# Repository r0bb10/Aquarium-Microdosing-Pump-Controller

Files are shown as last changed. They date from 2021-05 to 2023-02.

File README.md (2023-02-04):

# Aquarium-Microdosing-Pump-Controller
Software for an ESP8266 base aquarium micro-dosing pump. Controlled through a local webpage. Currently hard-coded to control a single pump, the hardware supports up to four. 

Required Libraries:
Adafruit I2C FRAM Library
Adafruit RTClib
ESPAsyncWebServer
ESPAsyncTCP
NTPClient
ESP8266TimerInterrupt
#Alepiro85 Changelog: ESP_EEPROM by j-watson

Also needed:
Setting up Arduino IDE to support uploading files to SPIFFS: https://randomnerdtutorials.com/install-esp8266-filesystem-uploader-arduino-ide/

Required Hardware:
MB85RC256V I2C FRAM. This is for saving configurations without constantly writing to internal memory to prevent excessive wearing. 
#Alepiro85 Changelog: from version 0.1A: Not necessary, it is possible to save parameters on EEPROM
DS3231 RTC. For keeping track of time if wifi is unavailable. 

Known Problems:
Need to redesign PCB to be smaller and cheaper. Software is hard-coded for a single pump. 
#Alepiro85 Changelog: from Version 0.1B: Software manages 4 pumps control

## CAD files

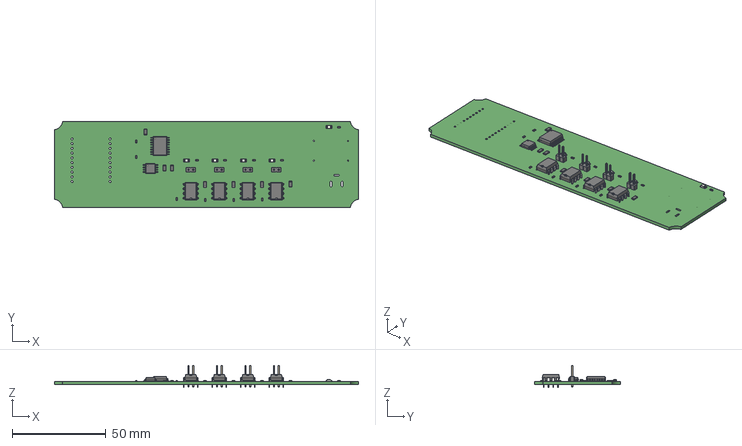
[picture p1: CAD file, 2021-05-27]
Hardware/Aquarium_Dosing_Pump_Controller/Aquarium_Dosing_Pump_Controller.step
162.6 x 45.7 x 11.8 mm

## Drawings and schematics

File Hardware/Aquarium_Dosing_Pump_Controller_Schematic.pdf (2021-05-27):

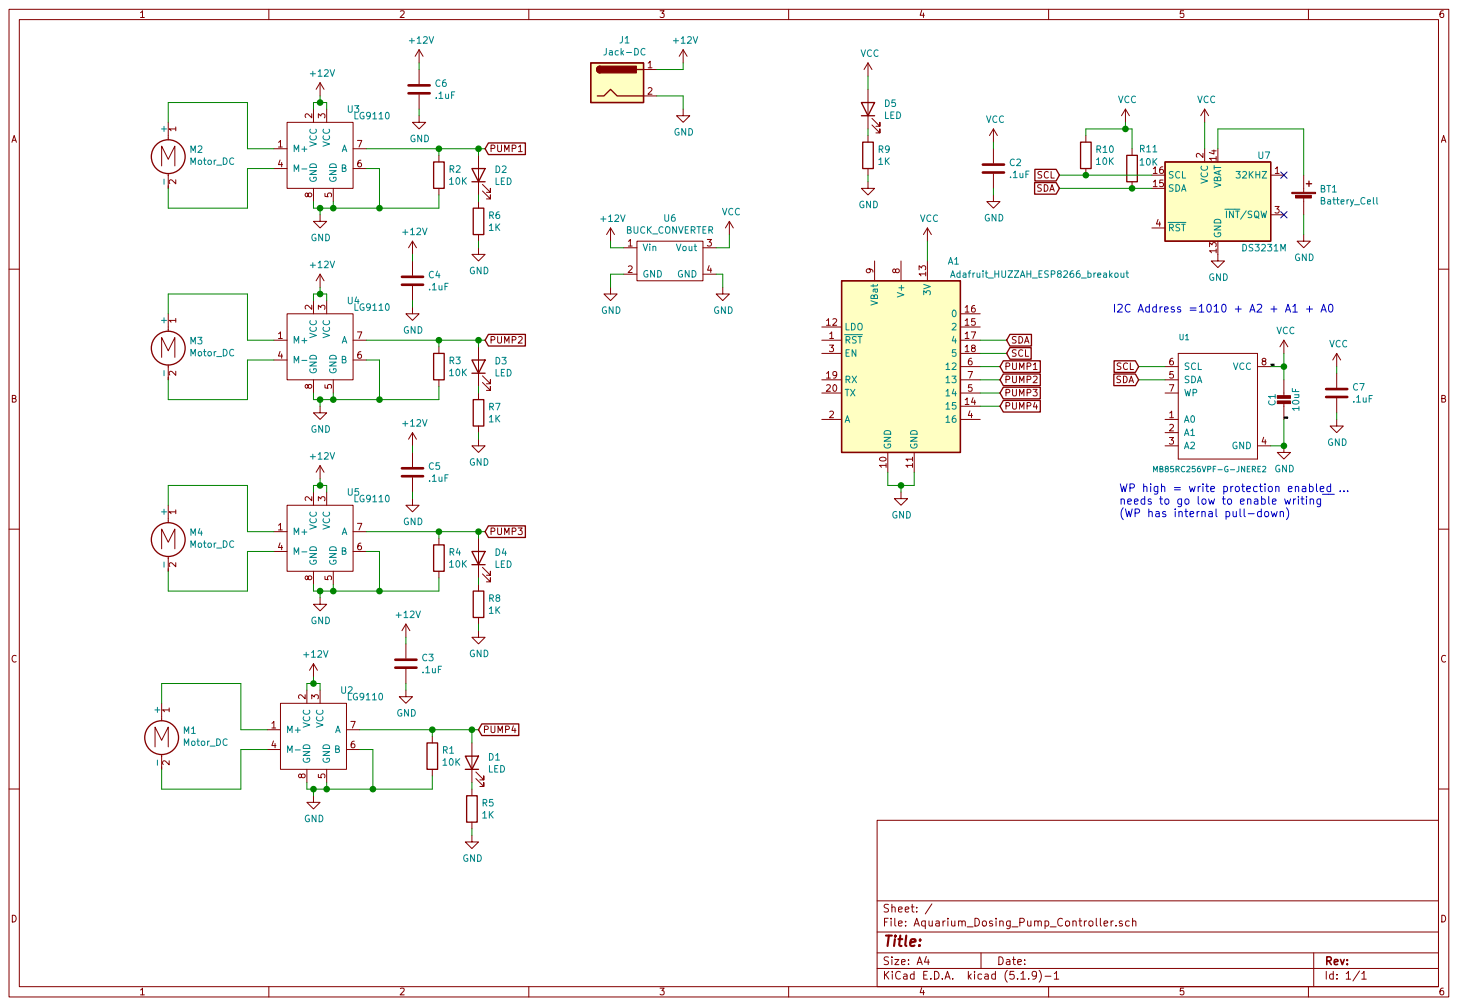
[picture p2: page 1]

VCC I2C Address =1010 + A2 + A1 + A0 WP high = write protection enabled ...

needs to go low to enable writing
(WP has internal pull-down)

File: Aquarium_Dosing_Pump_Controller.sch Sheet: / GND

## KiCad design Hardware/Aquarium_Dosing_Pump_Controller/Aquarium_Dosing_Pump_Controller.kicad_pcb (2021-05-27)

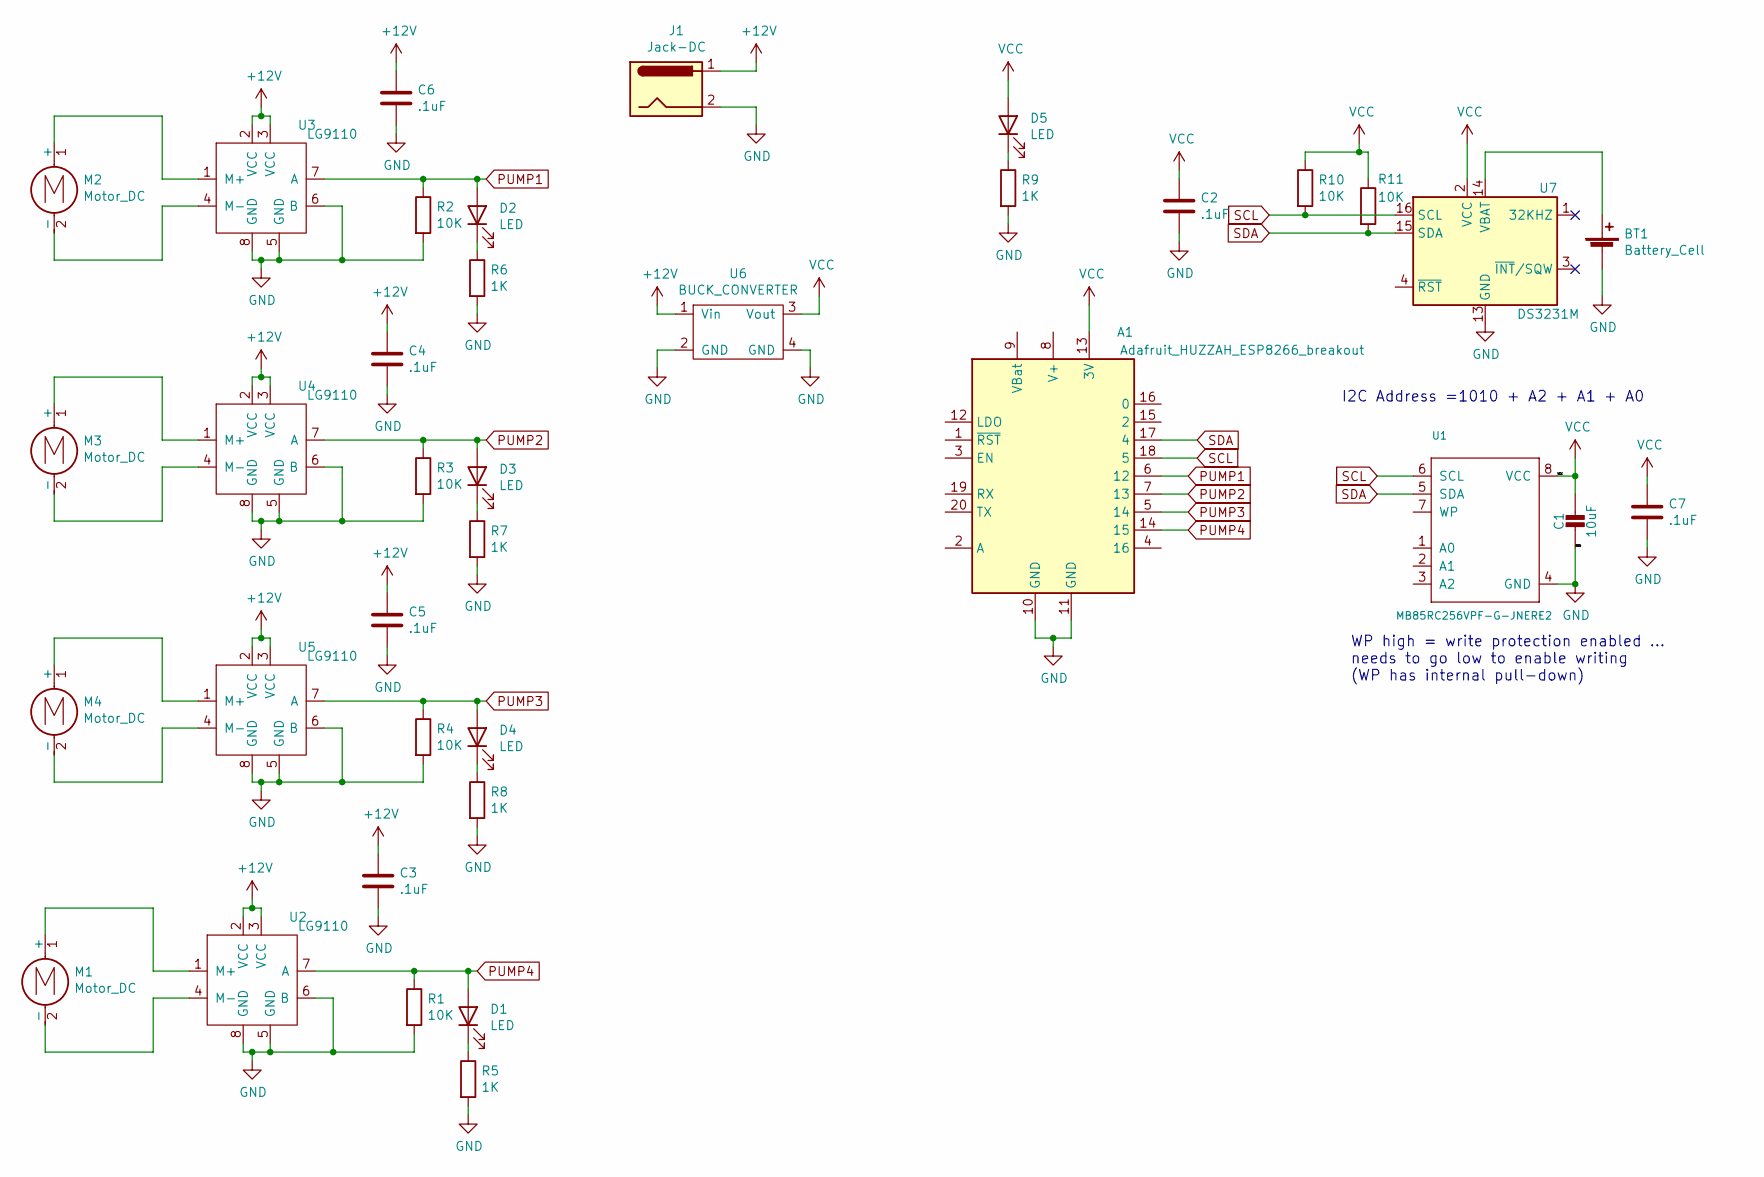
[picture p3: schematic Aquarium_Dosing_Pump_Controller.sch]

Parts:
A1: Adafruit_HUZZAH_ESP8266_breakout
BT1: Battery_Cell; CR1220
C1: 10uF; R_1206_3216Metric_Pad1.42x1.75mm_HandSolder
C2, C3, C4, C5, C6, C7: .1uF; R_1206_3216Metric_Pad1.42x1.75mm_HandSolder
D1, D2, D3, D4, D5: LED; LED_1206_3216Metric_Pad1.42x1.75mm_HandSolder
J1: Jack-DC; BarrelJack_Horizontal
M1, M2, M3, M4: Motor_DC; PinHeader_1x02_P2.54mm_Vertical
R1, R2, R3, R4, R10, R11: 10K; R_0603_1608Metric_Pad1.05x0.95mm_HandSolder
R5, R6, R7, R8, R9: 1K; R_0603_1608Metric_Pad1.05x0.95mm_HandSolder
U1: MB85RC256VPF-G-JNERE2; SOIJ-8_5.3x5.3mm_P1.27mm
U2, U3, U4, U5: LG9110; DIP-8_W7.62mm_LongPads
U6: BUCK_CONVERTER; Boost_Footprint
U7: DS3231M; SOIC-16W_7.5x10.3mm_P1.27mm

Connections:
+12V: C3.1, C4.1, C5.1, C6.1, J1.1, U2.2 (VCC), U2.3 (VCC), U3.2 (VCC), U3.3 (VCC), U4.2 (VCC), U4.3 (VCC), U5.2 (VCC), U5.3 (VCC), U6.1 (Vin)
GND: A1.10 (GND), A1.11 (GND), BT1.2 (-), C1.2, C2.2, C3.2, C4.2, C5.2, C6.2, C7.2, J1.2, R1.2, R2.2, R3.2, R4.2, R5.2, R6.2, R7.2, R8.2, R9.2, U1.4 (GND), U2.5 (GND), U2.6 (B), U2.8 (GND), U3.5 (GND), U3.6 (B), U3.8 (GND), U4.5 (GND), U4.6 (B), U4.8 (GND), U5.5 (GND), U5.6 (B), U5.8 (GND), U6.2 (GND), U6.4 (GND), U7.5 (GND), U7.6 (GND), U7.7 (GND), U7.8 (GND), U7.9 (GND), U7.10 (GND), U7.11 (GND), U7.12 (GND), U7.13 (GND)
unnamed: BT1.1 (+), U7.14 (VBAT)
unnamed: D1.1 (K), R5.1
unnamed: D2.1 (K), R6.1
unnamed: D3.1 (K), R7.1
unnamed: D4.1 (K), R8.1
unnamed: D5.1 (K), R9.1
unnamed: M1.1 (+), U2.1 (M+)
unnamed: M1.2 (-), U2.4 (M-)
unnamed: M2.1 (+), U3.1 (M+)
unnamed: M2.2 (-), U3.4 (M-)
unnamed: M3.1 (+), U4.1 (M+)
unnamed: M3.2 (-), U4.4 (M-)
unnamed: M4.1 (+), U5.1 (M+)
unnamed: M4.2 (-), U5.4 (M-)
PUMP1: A1.6 (12), D2.2 (A), R2.1, U3.7 (A)
PUMP2: A1.7 (13), D3.2 (A), R3.1, U4.7 (A)
PUMP3: A1.5 (14), D4.2 (A), R4.1, U5.7 (A)
PUMP4: A1.14 (15), D1.2 (A), R1.1, U2.7 (A)
SCL: A1.18 (5), R10.2, U1.6 (SCL), U7.16 (SCL)
SDA: A1.17 (4), R11.2, U1.5 (SDA), U7.15 (SDA)
VCC: A1.13 (3V), C1.1, C2.1, C7.1, D5.2 (A), R10.1, R11.1, U1.8 (VCC), U6.3 (Vout), U7.2 (VCC)

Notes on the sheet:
I2C Address =1010 + A2 + A1 + A0
WP high = write protection enabled ... needs to go low to enable writing~ (WP has internal pull-down)

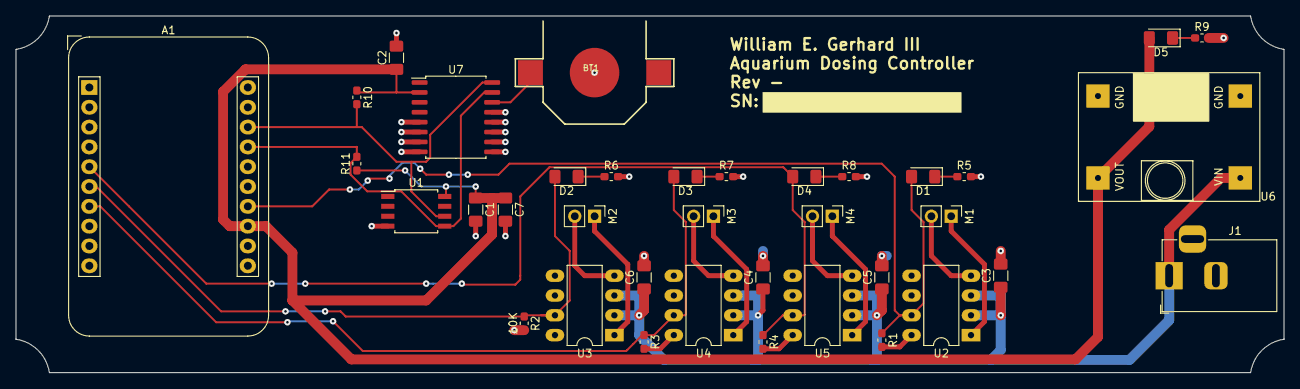
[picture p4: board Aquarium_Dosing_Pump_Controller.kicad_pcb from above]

Board: 2 copper layers, 162.6 x 45.7 mm, 37 parts (0 on the bottom side), 23 nets.

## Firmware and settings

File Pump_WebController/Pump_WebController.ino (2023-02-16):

//MODIFIED BY ALEPIRO85 - 2023-02-04
//BASED ON ORIGINAL CODE BY WILLIAMG42
//ON THE FORK OF THE MASTER OF EVERYTHING R0BB10

#define VERSION "0.1D"

//NOTES: IF AN EXTERNAL MEMORY IS USED, AS THE ORIGINAL PROJECT WANTS, YOU NEED TO DEFINE EXT_MEMORY (ACTUALLY NOT WORKING, HAVE TO BE DEBUGGED, IF YOU WANT TO DO IT UNCOMMENT NEXT CODE LINE)
//#define EXT_MEMORY     //Enable external memory

//NOTES: IF YOU WANT TO PRINT DEBUG STRINGS UN-COMMENT NEXT LINE)
#define DEBUG //Enable debug print

//NOTES: IF YOU WANT TO UNLOCK FOURTH PUMP (GPIO15 DOESN'T WORK PROPERLY NOW) UNCOMMENT NEXT CODE LINE
//#define P4_DEF //Enable debug print

// Import required libraries
#include <ESP8266WiFi.h>
#include <ESPAsyncTCP.h>
#include <Hash.h>
#include <FS.h>
#include <NTPClient.h>
#include <WiFiUdp.h>
#include <stdio.h>
#include <time.h>
#include <Wire.h>               //defined but not used
#include <RTClib.h>
#include <ESP8266mDNS.h>
#include <ArduinoOTA.h>
#include <string.h>
#include "pumpStruct.h"

//Select which include is correct
#ifdef EXT_MEMORY
  #include "Adafruit_FRAM_I2C.h"
#else
  #include <EEPROM.h>
  
  #define EEPROM_SIZE 4096
#endif

//WiFiManager, respect this order
#include <DNSServer.h>
#include <ESP8266WebServer.h>
#include "WiFiManager.h"        //https://github.com/tzapu/WiFiManager/archive/refs/tags/v2.0.15-rc.1.zip
#define WEBSERVER_H
#include "ESPAsyncWebSrv.h"

// These define's must be placed at the beginning before #include "ESP8266TimerInterrupt.h"
// _TIMERINTERRUPT_LOGLEVEL_ from 0 to 4
// Don't define _TIMERINTERRUPT_LOGLEVEL_ > 0. Only for special ISR debugging only. Can hang the system.
#define TIMER_INTERRUPT_DEBUG         0
#define _TIMERINTERRUPT_LOGLEVEL_     0

#include "ESP8266TimerInterrupt.h"
#include "ESP8266_ISR_Timer.h"

#define SDA_PIN 4
#define SCL_PIN 5

#define P1MEMADD 100
#define P2MEMADD 200
#define P3MEMADD 300
#define P4MEMADD 400
#define SETMEMADD 1000

// Set PUMP GPIO
const int gpio_PUMP1 = 12;
const int gpio_PUMP2 = 13;
const int gpio_PUMP3 = 14;
const int gpio_PUMP4 = 15;
const int pinReset = 16;
const int pinButton = 0;

pumpStruct pump1;
pumpStruct pump2;
pumpStruct pump3;
pumpStruct pump4;

Settings settings;
Settings tempSettings;
// Init ESP8266 timer 0
ESP8266Timer ITimer;
RTC_DS3231 rtc;

#define HW_TIMER_INTERVAL_MS        1000

// Define NTP Client to get time
WiFiUDP ntpUDP;
NTPClient timeClient(ntpUDP, "pool.ntp.org");

// Variable to save current epoch time
volatile unsigned long epochTime_Estimate;
unsigned long epochTime_Truth;
volatile unsigned int ticks = 0;
volatile unsigned int sync_ticks = 21600;
volatile unsigned int rtc_sync_ticks = 21600;

unsigned long startMillis = 0;
unsigned long stopMillis = 0;

const char* PARAM_DST = "DST";
const char* PARAM_TIMEZONEOFFSET = "timezoneOffset";

const char* PARAM_PUMP1CONTAINERVOLUME = "pump1ContainerVolume";
const char* PARAM_PUMP1DATETIME = "pump1DateTime";
const char* PARAM_PUMP1AMOUNT = "pump1DispensingAmount";
const char* PARAM_PUMP1DAY = "pump1day";
const char* PARAM_PUMP1ENABLE = "pump1ProgStatus";
const char* PARAM_PUMP1CALVOLUME = "pump1calibrationVolume";

const char* PARAM_PUMP2CONTAINERVOLUME = "pump2ContainerVolume";
const char* PARAM_PUMP2DATETIME = "pump2DateTime";
const char* PARAM_PUMP2AMOUNT = "pump2DispensingAmount";
const char* PARAM_PUMP2DAY = "pump2day";
const char* PARAM_PUMP2ENABLE = "pump2ProgStatus";
const char* PARAM_PUMP2CALVOLUME = "pump1calibrationVolume";

const char* PARAM_PUMP3CONTAINERVOLUME = "pump3ContainerVolume";
const char* PARAM_PUMP3DATETIME = "pump3DateTime";
const char* PARAM_PUMP3AMOUNT = "pump3DispensingAmount";
const char* PARAM_PUMP3DAY = "pump3day";
const char* PARAM_PUMP3ENABLE = "pump3ProgStatus";
const char* PARAM_PUMP3CALVOLUME = "pump1calibrationVolume";

const char* PARAM_PUMP4CONTAINERVOLUME = "pump4ContainerVolume";
const char* PARAM_PUMP4DATETIME = "pump4DateTime";
const char* PARAM_PUMP4AMOUNT = "pump4DispensingAmount";
const char* PARAM_PUMP4DAY = "pump4day";
const char* PARAM_PUMP4ENABLE = "pump4ProgStatus";
const char* PARAM_PUMP4CALVOLUME = "pump1calibrationVolume";

const int MAX_STRUCT_SIZE = 44; //TODO: check it by strlen
char buffer[MAX_STRUCT_SIZE];
char strBuf[MAX_STRUCT_SIZE];
boolean commitSucc=false;
boolean rtcWorking=false;

// Create AsyncWebServer object on port 80
AsyncWebServer server(80);
#ifdef EXT_MEMORY
Adafruit_FRAM_I2C fram = Adafruit_FRAM_I2C();
#else
//Nothing?
#endif

AsyncEventSource events("/events");

void notFound(AsyncWebServerRequest *request) {
  request->send(404, "text/plain", "Not found");
}

// Function that gets current epoch time
unsigned long getTime() {
  timeClient.update();
  unsigned long now = timeClient.getEpochTime();
  return now;
}

void ICACHE_RAM_ATTR TimerHandler()
{
  epochTime_Estimate = epochTime_Estimate + 1;
  ticks = ticks + 1;
  sync_ticks = sync_ticks +1;
  rtc_sync_ticks = rtc_sync_ticks +1;
}



void initRTC()
{
  if (! rtc.begin()) {
    Serial.println("Couldn't find RTC, proceed with internal clock");
    Serial.flush();
    rtcWorking = false;
    timeClient.begin();
  }
  else
  {
    rtcWorking = true;
  }

  if ((rtc.lostPower())&&(rtcWorking == true)) {
    Serial.println("RTC lost power, let's set the time!");
    // When time needs to be set on a new device, or after a power loss, the
    // following line sets the RTC to the date & time this sketch was compiled
    rtc.adjust(DateTime(F(__DATE__), F(__TIME__)));
    // This line sets the RTC with an explicit date & time, for example to set
    // January 21, 2014 at 3am you would call:
    // rtc.adjust(DateTime(2014, 1, 21, 3, 0, 0));
  }
}

// Replaces placeholder with stored values
String processor(const String& var)
{
  if (var == PARAM_PUMP1CALVOLUME)
  {
    return String(pump1.calibrationVolumeL);
  }
  else if (var == PARAM_PUMP2CALVOLUME)
  {
    return String(pump2.calibrationVolumeL);
  }
  else if (var == PARAM_PUMP3CALVOLUME)
  {
    return String(pump3.calibrationVolumeL);
  }
  else if (var == PARAM_PUMP4CALVOLUME)
  {
    return String(pump4.calibrationVolumeL);
  }
  else if (var == PARAM_TIMEZONEOFFSET)
  {
    return String(settings.timezoneOffset / 3600);
  }
  else if (var == PARAM_PUMP1CONTAINERVOLUME)
  {
    return String(pump1.containerVolume);
  }
  else if (var == PARAM_PUMP1AMOUNT)
  {
    return String(pump1.volumePump_mL);
  }
  else if (var == PARAM_PUMP1DATETIME)
  {
    if(pump1.nextRuntime == 0)
    {
      return String("NA");
    }
    else
    {
      DateTime dt (pump1.nextRuntime+settings.timezoneOffset+(3600*settings.DST));
      sprintf(strBuf, "%i-%02i-%02i, %02i:%02i:%02i DST:%i", dt.year(), dt.month(), dt.day(), dt.hour(), dt.minute(), dt.second(), settings.DST );
      return String(strBuf);
    }    
  }
  else if (var == PARAM_PUMP1DAY)
  {
    return String(pump1.dayDelay);
  }
  else if (var == PARAM_PUMP1ENABLE) {
    if (pump1.programEnable)
    {
      return String("Enabled");
    }
    else
    {
      return String("Disabled");
    }
  }
  else if (var == PARAM_PUMP2CONTAINERVOLUME)
  {
    return String(pump2.containerVolume);
  }
  else if (var == PARAM_PUMP2AMOUNT)
  {
    return String(pump2.volumePump_mL);
  }
  else if (var == PARAM_PUMP2DATETIME)
  {
    if(pump2.nextRuntime == 0)
    {
      return String("NA");
    }
    else
    {
      DateTime dt (pump2.nextRuntime+settings.timezoneOffset+(3600*settings.DST));
      sprintf(strBuf, "%i-%02i-%02i, %02i:%02i:%02i DST:%i", dt.year(), dt.month(), dt.day(), dt.hour(), dt.minute(), dt.second(), settings.DST );
      return String(strBuf);
    }    
  }
  else if (var == PARAM_PUMP2DAY)
  {
    return String(pump2.dayDelay);
  }
  else if (var == PARAM_PUMP2ENABLE) {
    if (pump2.programEnable)
    {
      return String("Enabled");
    }
    else
    {
      return String("Disabled");
    }
  }
  else if (var == PARAM_PUMP3CONTAINERVOLUME)
  {
    return String(pump3.containerVolume);
  }
  else if (var == PARAM_PUMP3AMOUNT)
  {
    return String(pump3.volumePump_mL);
  }
  else if (var == PARAM_PUMP3DATETIME)
  {
    if(pump3.nextRuntime == 0)
    {
      return String("NA");
    }
    else
    {
      DateTime dt (pump3.nextRuntime+settings.timezoneOffset+(3600*settings.DST));
      sprintf(strBuf, "%i-%02i-%02i, %02i:%02i:%02i DST:%i", dt.year(), dt.month(), dt.day(), dt.hour(), dt.minute(), dt.second(), settings.DST );
      return String(strBuf);
    }    
  }
  else if (var == PARAM_PUMP3DAY)
  {
    return String(pump3.dayDelay);
  }
  else if (var == PARAM_PUMP3ENABLE) {
    if (pump3.programEnable)
    {
      return String("Enabled");
    }
    else
    {
      return String("Disabled");
    }
  }
  else if (var == PARAM_PUMP4CONTAINERVOLUME)
  {
    return String(pump4.containerVolume);
  }
  else if (var == PARAM_PUMP4AMOUNT)
  {
    return String(pump4.volumePump_mL);
  }
  else if (var == PARAM_PUMP4DATETIME)
  {
    if(pump4.nextRuntime == 0)
    {
      return String("NA");
    }
    else
    {
      DateTime dt (pump4.nextRuntime+settings.timezoneOffset+(3600*settings.DST));
      sprintf(strBuf, "%i-%02i-%02i, %02i:%02i:%02i DST:%i", dt.year(), dt.month(), dt.day(), dt.hour(), dt.minute(), dt.second(), settings.DST );
      return String(strBuf);
    }    
  }
  else if (var == PARAM_PUMP4DAY)
  {
    return String(pump4.dayDelay);
  }
  else if (var == PARAM_PUMP4ENABLE) {
    if (pump4.programEnable)
    {
      return String("Enabled");
    }
    else
    {
      return String("Disabled");
    }
  }
  else
  {
    return String();
  }
}

void configModeCallback (WiFiManager *myWiFiManager) {
  Serial.println("Entered config mode");
  Serial.println(WiFi.softAPIP());
  //if you used auto generated SSID, print it
  Serial.println(myWiFiManager->getConfigPortalSSID());
}

void setup() {
  // Serial port for debugging purposes
  Serial.begin(115200);
  Serial.println("Initialize System");
  initRTC();
  #ifdef EXT_MEMORY
    if (fram.begin(0x50))
    {  // you can stick the new i2c addr in here, e.g. begin(0x51);
     Serial.println("Found I2C FRAM");
    }
    else
    {
     Serial.println("I2C FRAM not identified ... check your connections?\r\n");
     Serial.println("Will continue in case this processor doesn't support repeated start\r\n");
    }
  #else
    pinMode(SDA_PIN,OUTPUT);
    pinMode(SCL_PIN,OUTPUT);
    EEPROM.begin(EEPROM_SIZE);
  #endif

  pinMode(gpio_PUMP1, OUTPUT);
  digitalWrite(gpio_PUMP1, LOW);
  pinMode(gpio_PUMP2, OUTPUT);
  digitalWrite(gpio_PUMP2, LOW);
  pinMode(gpio_PUMP3, OUTPUT);
  digitalWrite(gpio_PUMP3, LOW);
  pinMode(gpio_PUMP4, OUTPUT);
  digitalWrite(gpio_PUMP4, LOW);  

  WiFiManager wifiManager;
  wifiManager.setAPCallback(configModeCallback);
  WiFi.hostname("MicroDoser");

  if(!wifiManager.autoConnect("MicroDoser")) {
    Serial.println("Connection Timout");
    //reset and try again, or maybe put it to deep sleep
    ESP.reset();
    delay(1000);
  } 

  Serial.println(F("WIFIManager connected!"));

  // Port defaults to 8266
  // ArduinoOTA.setPort(8266);

  // Hostname defaults to esp8266-[ChipID]
  // ArduinoOTA.setHostname("myesp8266");

  // No authentication by default
  // ArduinoOTA.setPassword((const char *)"123");

  ArduinoOTA.onStart([]() {
    Serial.println("Start");
  });
  ArduinoOTA.onEnd([]() {
    Serial.println("\nEnd");
  });
  ArduinoOTA.onProgress([](unsigned int progress, unsigned int total) {
    Serial.printf("Progress: %u%%\r", (progress / (total / 100)));
  });
  ArduinoOTA.onError([](ota_error_t error) {
    Serial.printf("Error[%u]: ", error);
    if (error == OTA_AUTH_ERROR) Serial.println("Auth Failed");
    else if (error == OTA_BEGIN_ERROR) Serial.println("Begin Failed");
    else if (error == OTA_CONNECT_ERROR) Serial.println("Connect Failed");
    else if (error == OTA_RECEIVE_ERROR) Serial.println("Receive Failed");
    else if (error == OTA_END_ERROR) Serial.println("End Failed");
  });
  ArduinoOTA.begin();

  // Initialize SPIFFS
  if (!SPIFFS.begin())
  {
   Serial.println("An Error has occurred while mounting SPIFFS");
   return;
  }  
  
  DateTime now_Time;
  if(rtcWorking == true)
  {
    DateTime now_Time = rtc.now(); 
  }
  else
  {
    now_Time = timeClient.update();
    Serial.println(timeClient.getFormattedTime());
  }
  epochTime_Truth = now_Time.unixtime();
  
  Serial.println(epochTime_Truth);
  
  epochTime_Estimate = epochTime_Truth;
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
void loop() {
  ArduinoOTA.handle();

  // Allow MDNS processing
  MDNS.update();

  if (ticks > 0)
  {
    events.send(String(epochTime_Estimate).c_str(),"currentTime",millis());
    ticks = 0;
  }
  if (sync_ticks > settings.time_sync_check)
  {
    sync_ticks = 0;
    DateTime now_Time;
    if(rtcWorking == true)
    {
      now_Time = rtc.now(); 
    }
    else
    {
      now_Time =timeClient.update();
      Serial.println(timeClient.getFormattedTime());
    }
    epochTime_Estimate = now_Time.unixtime();     
  }
  if (rtc_sync_ticks > settings.rtc_time_sync_check)
  {
    rtc_sync_ticks = 0;
    unsigned long time_truth;
    if(rtcWorking == true)
    {
       time_truth = getTime();
    }
    else
    {
       time_truth = timeClient.update();
       Serial.println(timeClient.getFormattedTime());
    }


    
    if (time_truth > epochTime_Estimate-1000)
    {
      epochTime_Estimate = time_truth;      
      if(rtcWorking == true)
      {
         rtc.adjust(DateTime(time_truth));
      }
      else
      {
         time_truth = timeClient.update();
         Serial.println(timeClient.getFormattedTime());
      }
    }   
  }

  checkPump(pump1, P1MEMADD);
  checkPump(pump2, P2MEMADD);
  checkPump(pump3, P3MEMADD);
  checkPump(pump4, P4MEMADD);

  //WIP: Implement Reset to Defaults
  factoryReset();
}

void checkPump(pumpStruct pump, int address)
{
  if (pump.nextRuntime  ==  epochTime_Estimate && pump.programEnable == true && pump.containerVolume > 0)
  {
    digitalWrite(pump.motor_GPIO, HIGH);
    pump.previousRuntime =  pump.nextRuntime;
    pump.nextRuntime = pump.nextRuntime + (pump.dayDelay) * 86400;
    pump.totalvolumePumped_mL += pump.volumePump_mL;
    pump.containerVolume -= pump.volumePump_mL;
    #ifdef EXT_MEMORY    
      fram.write(address, pump);
    #else
      EEPROM.put(address, pump);
      commitSucc = EEPROM.commit();
    #endif
    #ifdef DEBUG
      memcpy(buffer, &pump, sizeof(buffer));
      Serial.println("Chars check");
      Serial.println(buffer);
    #endif
    delay(round((pump.volumePump_mL * pump.CAL_pumpmS) / pump.calibrationVolumeL));
    Serial.print(round((pump.volumePump_mL * pump.CAL_pumpmS) / pump.calibrationVolumeL));
    digitalWrite(pump.motor_GPIO, LOW);
    events.send(String(pump.nextRuntime).c_str(),"pumpnextDatetime",millis());
  }
  else if ((pump.nextRuntime  < epochTime_Estimate) && (pump.programEnable == true))
  {
    pump.nextRuntime = pump.nextRuntime + (86400*pump.dayDelay);
  }
}

pumpStruct loadPump(const int address, int motor)
{
  pumpStruct pump;
  strcpy(pump.valid_read, "NaN");
  
  #ifdef EXT_MEMORY
    fram.read(address, pump);
  #else
    EEPROM.get(address, pump);
  #endif
  
  #ifdef DEBUG
    itoa(address/100, buffer, 10);
    Serial.println("************************");
    sprintf(strBuf, "Pump number %s", buffer);
    Serial.println(strBuf);
  #endif    

  if((pump.valid_read[0] == '$')&&(pump.valid_read[1] == '$')&&(pump.valid_read[2] == '$'))
  {
    #ifdef DEBUG
      Serial.println("Values read correctly");
      
      itoa(pump.CAL_pumpmS, buffer, 10);
      sprintf(strBuf, "Calibration in mS %s", buffer);
      Serial.println(strBuf);

      itoa(pump.previousRuntime, buffer, 10);
      sprintf(strBuf, "Last time ran %s", buffer);
      Serial.println(strBuf);

      itoa(pump.nextRuntime, buffer, 10);
      sprintf(strBuf, "Next time run %s", buffer);
      Serial.println(strBuf);

      itoa(pump.dayDelay, buffer, 10);
      sprintf(strBuf, "Delay in days %s", buffer);
      Serial.println(strBuf);

      itoa(pump.volumePump_mL, buffer, 10);
      sprintf(strBuf, "Pump volume %s", buffer);
      Serial.println(strBuf);

      itoa(pump.totalvolumePumped_mL, buffer, 10);
      sprintf(strBuf, "Total volume pumped %s", buffer);
      Serial.println(strBuf);
      
      itoa(pump.containerVolume, buffer, 10);
      sprintf(strBuf, "Container volume %s", buffer);
      Serial.println(strBuf);
      
      itoa(pump.motor_GPIO, buffer, 10);
      sprintf(strBuf, "Motor GPIO %s", buffer);
      Serial.println(strBuf);
    
      itoa(pump.programEnable, buffer, 10);
      sprintf(strBuf, "Program enabled %s", buffer);
      Serial.println(strBuf);
    #endif
  }
  else
  {
    #ifdef DEBUG
      Serial.println("Values not present or wrong memory sector, resetting values");
    #endif
    
    pump.CAL_pumpmS=0;            //time in mSecs to run pump 100 mL of fluid                    2bytes
    pump.previousRuntime=0;       //last time the pump ran in Epoch time (S)                     4bytes
    pump.nextRuntime=0;           //next time the pump needs to run in Epoch time (S)            4bytes
    pump.dayDelay=1;              //how many days until the pump runs again                      2bytes
    pump.volumePump_mL = 1;       //                                                             2bytes
    pump.totalvolumePumped_mL=0;  //running total of all the liquid the pump has pumped (mL)     2bytes
    pump.containerVolume=0;       //amount of in pump reservoir.                                 2bytes
    pump.motor_GPIO = motor;      //                                                             2bytes
    pump.programEnable = false;   //                                                             1byte
    strcpy(pump.valid_read, "$$$");
    
    EEPROM.put(address, pump);
    commitSucc = EEPROM.commit();
    #ifdef DEBUG
      Serial.println("Writing new values on EEPROM");
      Serial.println(commitSucc);
    #endif
  }
  return pump;
}

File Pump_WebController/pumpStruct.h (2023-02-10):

#ifndef PUMPSTRUCT_H
#define PUMPSTRUCT_H

struct pumpStruct {
  char valid_read[4];//                                                           3byte
  int CAL_pumpmS = 0; //time in mSecs to run pump 100 mL of fluid                                   2bytes
  unsigned long previousRuntime = 0; //last time the pump ran in Epoch time (S)                     4bytes
  unsigned long nextRuntime = 0; //next time the pump needs to run in Epoch time (S)                4bytes
  int dayDelay = 10; //how many days until the pump runs again                                      2bytes
  float volumePump_mL = 1;  //                                                                    2bytes
  float totalvolumePumped_mL = 0; //running total of all the liquid the pump has pumped (mL)        2bytes
  float containerVolume = 0; //amount of in pump reservoir.                                         2bytes
  int motor_GPIO = 0;//                                                                           2bytes
  bool programEnable = false;//                                                                   1byte
  float calibrationVolumeL = 20.0;//                                                              2bytes
}; //                                                                 total size needed in rom   24bytes


struct Settings {
  char valid_read[4];//                                                           3bytes
  int timezoneOffset = -18000;//                                                                  2bytes
  bool DST = 0;//                                                                                 1byte
  unsigned int time_sync_check = 600;//                                                           2bytes
  unsigned int rtc_time_sync_check = 21600;//                                                     2bytes
};//                                                                   total size needed in rom   12bytes

#endif

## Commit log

2021-05-27 Intial Commit
    Adds current working version of code. Supports only 1 dosing pump.
2021-05-27 Added hardware files
    Added the Kicad files for the hardware.
    [Aquarium_Dosing_Pump_Controller-B_Cu.gbl, Aquarium_Dosing_Pump_Controller-B_Mask.gbs, Aquarium_Dosing_Pump_Controller-B_SilkS.gbo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]
2021-05-27 Added Schematic PDF of Hardware
2021-06-17 Updated time sync to only use RTC
    Internal timer will only be updated from I2C rtc module, and RTC module will be updated from online time server when valid. This fixed a bug where sometimes the controller would have the incorrect time.
    [Pump_WebController.ino, pumpStruct.h]
2023-02-04 write many times bug verifing, little code indentation improvement
    [Pump_WebController.ino]
2023-02-04 4 pumps management, indentation improvement
2023-02-05 multiple memory write solved, set table in status web page
    [Pump_WebController.ino]
2023-02-06 Update index.html
    pump management in table design
2023-02-07 EEPROM test and debug strings print by DEBUG declaration
2023-02-08 EEPROM reading inserted
2023-02-08 write and read of the 4 pumps structures in eeprom
2023-02-09 struct corrected and check EEPROM from Bool to Char
    [Pump_WebController.ino, pumpStruct.h]
2023-02-09 almost connect ino and html variables, some js problem on 2nd value change
    [Pump_WebController.ino]
2023-02-12 calibration timers and buttons fixed
2023-02-13 Update Pump_WebController.ino
    get values from webpage test
